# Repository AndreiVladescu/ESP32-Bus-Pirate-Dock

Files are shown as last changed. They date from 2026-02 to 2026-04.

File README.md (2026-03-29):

# ESP32-Bus-Pirate-Dock

Open-source carrier board for the Espressif ESP32-S3 DevKit, designed to complement the [ESP32-Bus-Pirate](https://github.com/geo-tp/ESP32-Bus-Pirate) project.

## Overview

PCB Top

ESP32-Bus-Pirate-Dock is a hardware dock/carrier board for the ESP32-S3 DevKit. It provides level and voltage translation between the 3.3V ESP32-S3 and external peripherals, with support for 1.8V, 3.3V, and 5V operation.

The design is intended to work with original ESP32-S3-DevKitC-1, as well as the wider devkit clones from third party suppliers.

## Hardware status

Current hardware revision: V3

The markings on the PCB for the serial number `V0-YYWW-XXXXX` are as follows: 
- version `0`
- year and week number when these PCBs were produced
- incrementing number of the current batch

An example PCB with these markings would be `V3-2613-00512`, where:
- version number is `3`
- the year is `2026`, and the week is `13`
- this is the `512th` PCB made in that respective week

## Repository contents

- `dock/kicad/` — KiCad design files
- `dock/gerbers/` — PCB fabrication outputs
- `dock/schematic.pdf` — exported schematic reference
- `dock/BOM.csv` — bill of materials
- `3d_models/` — 3D models for the dock and a WIP case
- `images/` — presentation images

## Open-source scope

This repository open-sources the dock hardware design, including:
- schematic and PCB layout source files
- fabrication outputs
- bill of materials
- project documentation and images included in this repository

## Required external parts

This project requires an **ESP32-S3 DevKit to be procured separately by the end user**.

The ESP32-S3 DevKit is a third-party board/module and is **not included** as part of this hardware design repository unless explicitly stated. Vendor silicon, datasheets, trademarks, and separately licensed third-party materials remain the property of their respective owners.

These boards can be acquired through the official Espressif manufacturer and it's stores, or through other third-party websites. If not buying a genuine one,
make sure the dimensions fit one of the header pins on the board.

## PCB Design

### Top View
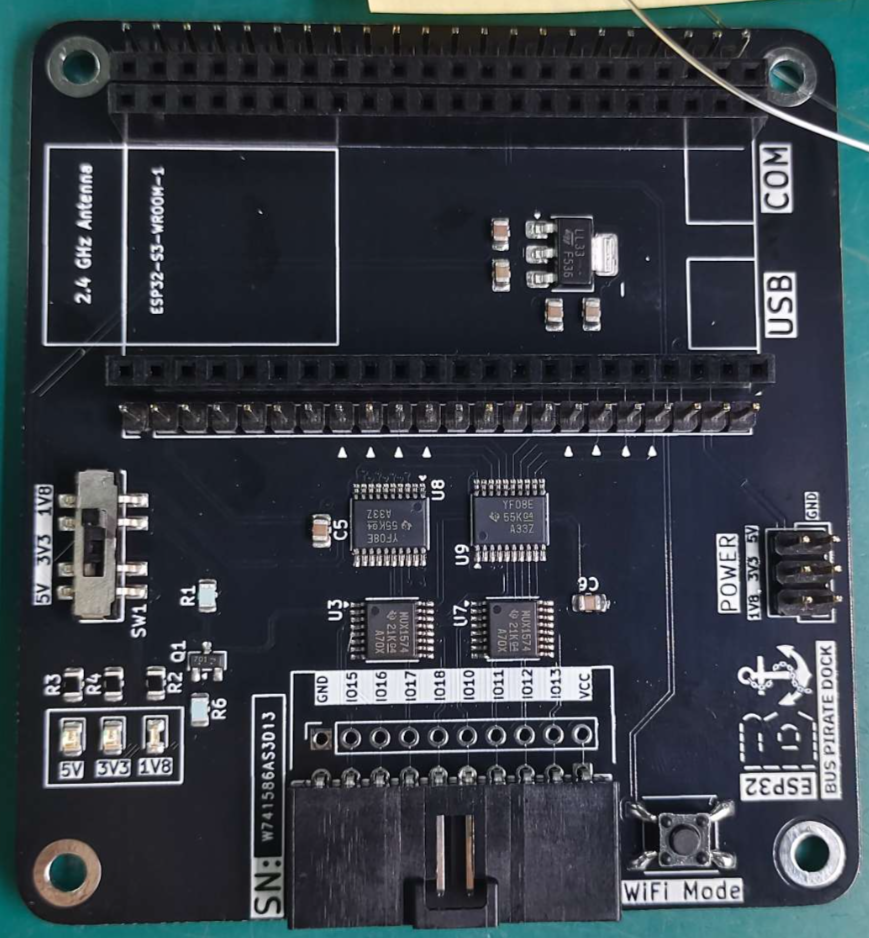
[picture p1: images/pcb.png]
PCB Top


## Current Prototype

### Front Rendering
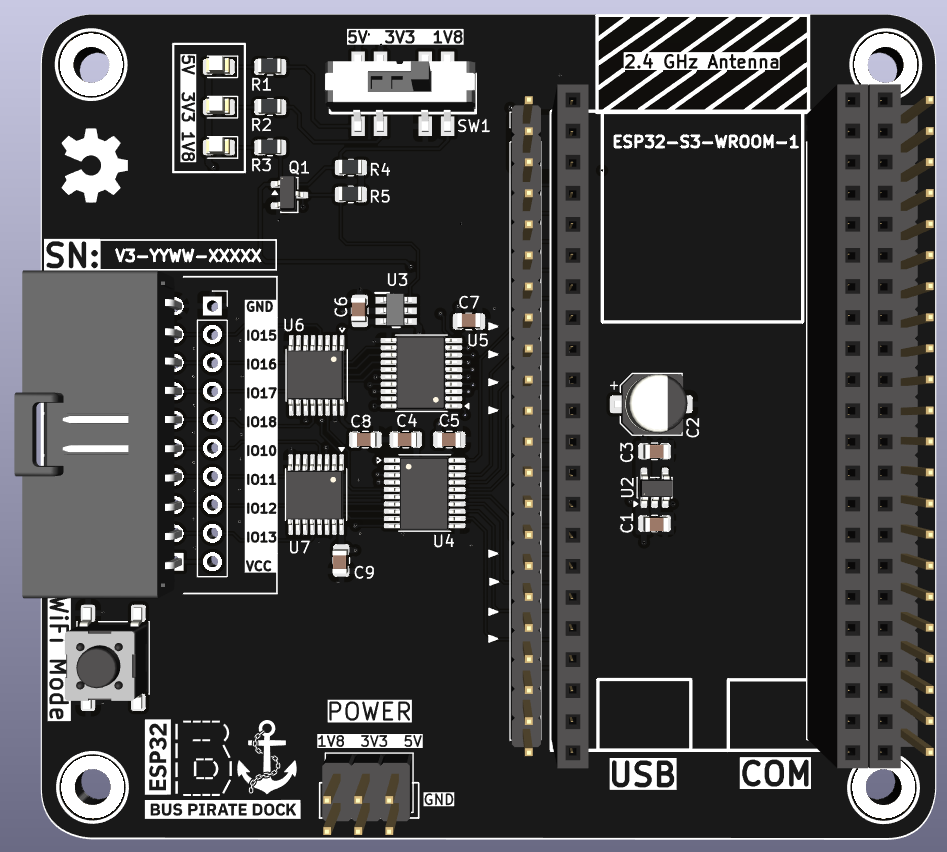
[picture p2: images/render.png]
Front Rendering


### Back Rendering
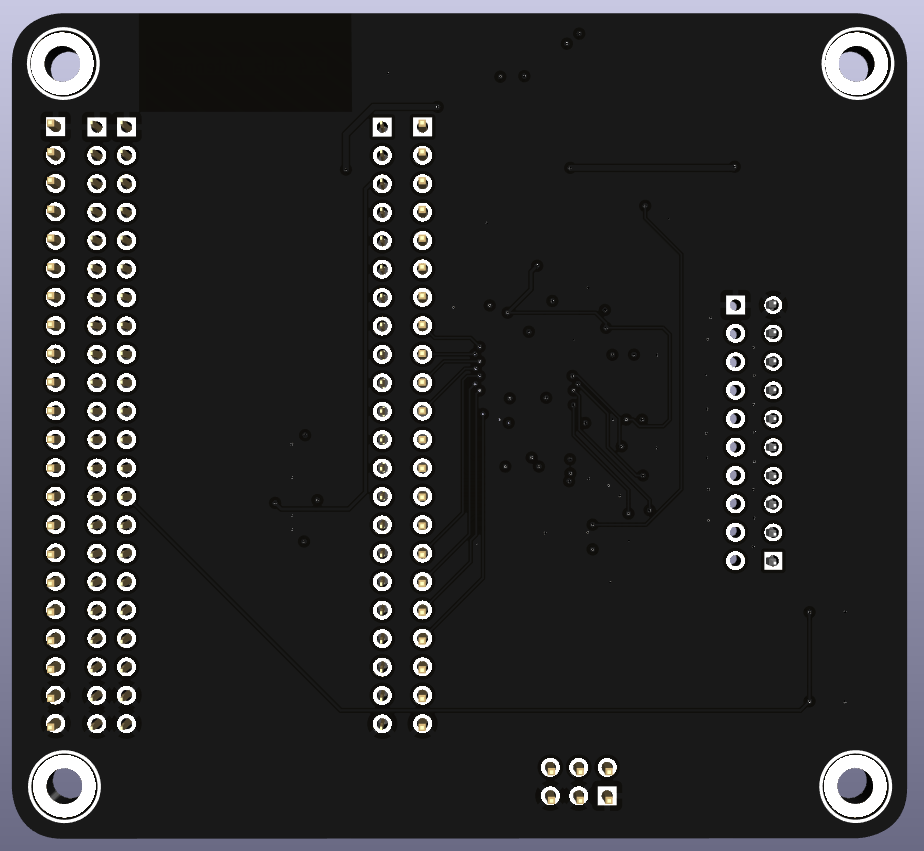
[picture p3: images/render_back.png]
Back Rendering


## Manufacturing and assembly

To fabricate the PCB, use the files in `dock/gerbers/`.

To inspect or modify the design, use the original KiCad source files in `dock/kicad/`.

To source components, use `dock/BOM.csv`.

## Case Design

The case for the ESP32 Bus Pirate Dock is still a work in progress. The current design uses two pieces, which can be printed using an FDM printer with
a 0.4 nozzle.

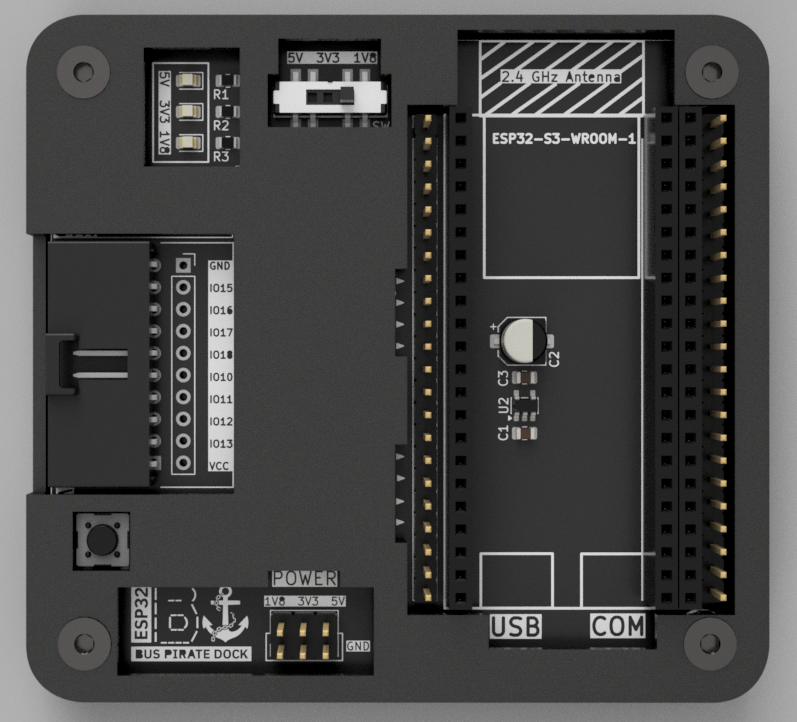
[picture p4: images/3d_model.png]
Case 3D Model

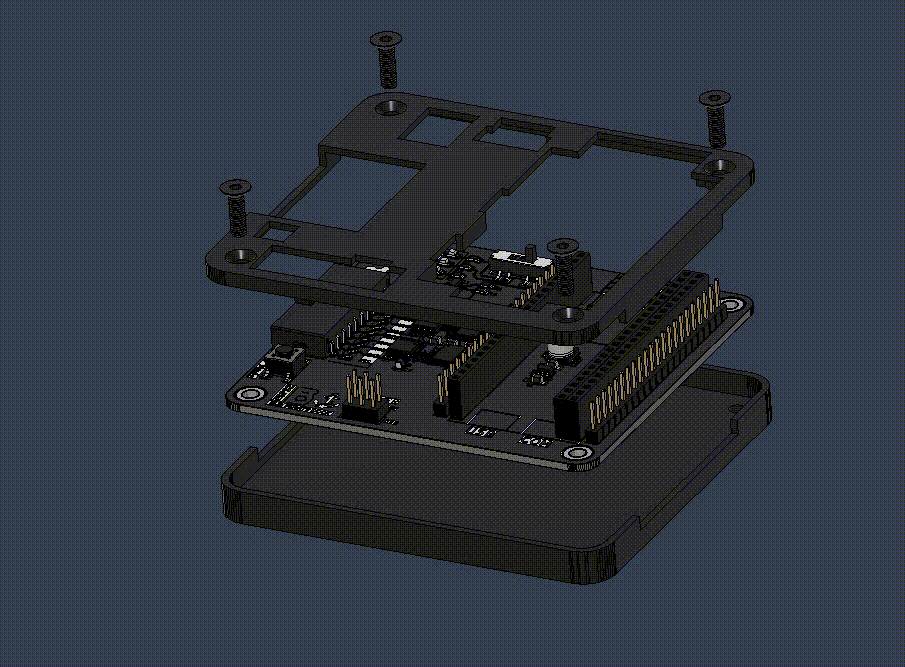
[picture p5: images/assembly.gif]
Dock Assembly


## License

Hardware design files in this repository are licensed under the CERN-OHL-W-2.0 license.
See [LICENSE](LICENSE) for the full license text.

Documentation and images in this repository are licensed under CC BY 4.0 unless otherwise noted.

Any third-party trademarks, datasheets, and separately licensed materials remain the property of their respective owners.

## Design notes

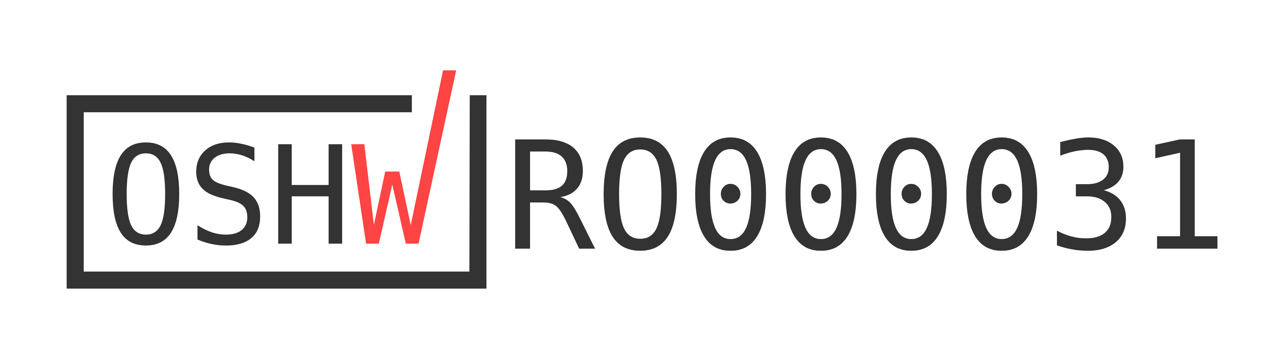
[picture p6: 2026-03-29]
images/certification-mark-RO000031-wide.png

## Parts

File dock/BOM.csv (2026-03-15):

Id | Designator | Footprint | Quantity | Designation | Supplier and ref
1 | SW_1 | SW_SPST_PTS645Sx43SMTR92 | 1 | SW_BOOT
2 | D1 | LED_0805_2012Metric | 1 | RED
3 | C7,C5,C4,C6 | C_0805_2012Metric | 4 | 0.1u
4 | C1,C3 | C_0805_2012Metric | 2 | 1u
5 | C2 | CP_Elec_5x4.5 | 1 | 22u
6 | CN1 | CONN-TH_HX25418-10WA | 1 | HX25418-10WA
7 | J1,J6,J5 | PinSocket_1x22_P2.54mm_Vertical | 3 | Conn_01x22
8 | D2 | LED_0805_2012Metric | 1 | ORANGE
9 | J4,J2 | PinHeader_1x22_P2.54mm_Vertical | 2 | Conn_01x22
10 | U2 | SOT-23-5 | 1 | TLV75518PDBV
11 | C9,C8 | C_0805_2012Metric | 2 | 4.7u
12 | U3 | SOT95P280X145-6N | 1 | TS5A3157DBVR
13 | Q1 | SOT-23 | 1 | 2N7002
14 | R3,R1,R2 | R_0805_2012Metric | 3 | 1k
15 | D3 | LED_0805_2012Metric | 1 | BLUE
16 | R5,R4 | R_0805_2012Metric | 2 | 10k
17 | U7,U6 | TSSOP-16_4.4x5mm_P0.65mm | 2 | TMUX1574PW
18 | SW1 | SW-SMD_8P-L13.0-W3.5-P2.00 | 1 | TA-3532S-A2
19 | U4,U5 | Texas_PW0020A_TSSOP-20_4.4x6.5mm_P0.65mm | 2 | TXS0108EPW
20 | J7 | PinHeader_2x03_P2.54mm_Vertical | 1 | Conn_02x03

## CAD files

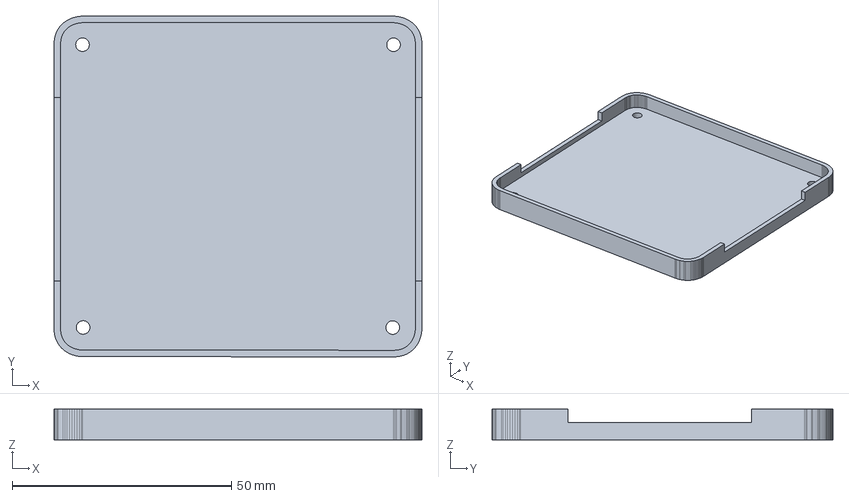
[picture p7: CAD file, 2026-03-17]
dock/3d_models/Bottom Case.step
84.0 x 77.8 x 7.01 mm

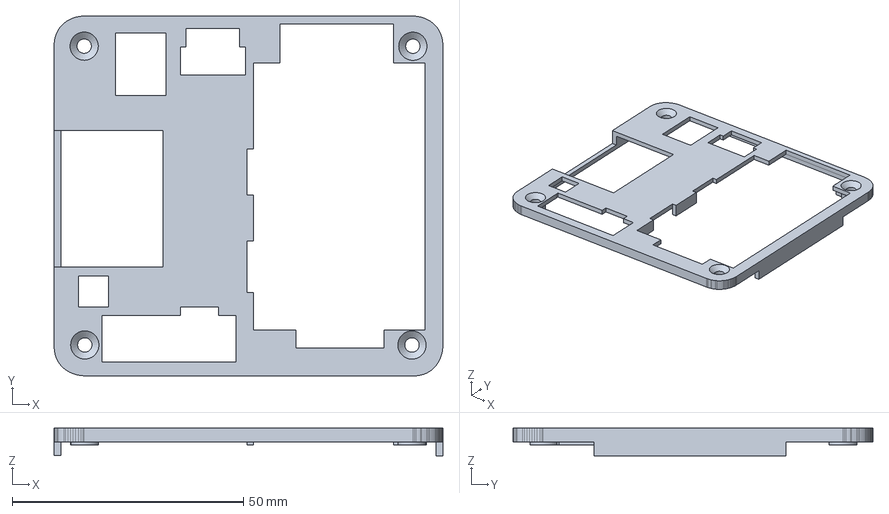
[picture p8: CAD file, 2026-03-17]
dock/3d_models/Top Case.step
84.0 x 77.8 x 6.00 mm

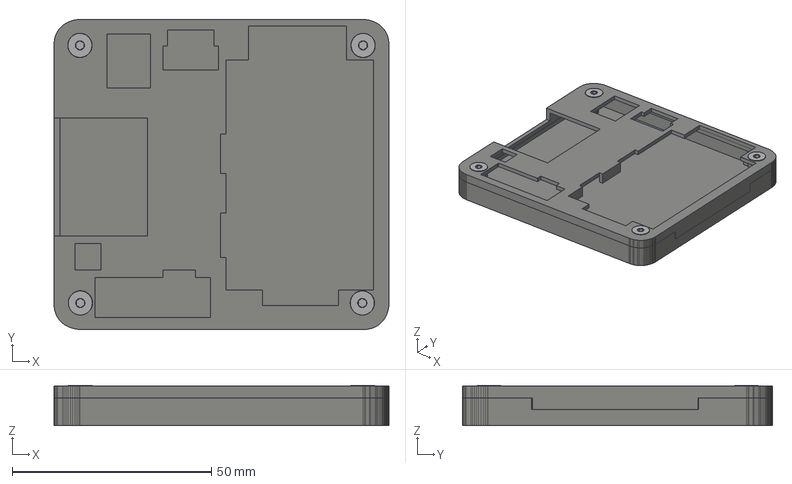
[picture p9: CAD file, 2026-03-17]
dock/3d_models/enclosure.step
84.0 x 77.8 x 10.2 mm
91294A132_Black-Oxide Alloy Steel Hex Drive Flat Head Screw x 4
Bottom Case
Top Case

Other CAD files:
dock/3d_models/Bottom Case.stl
dock/3d_models/Top Case.stl

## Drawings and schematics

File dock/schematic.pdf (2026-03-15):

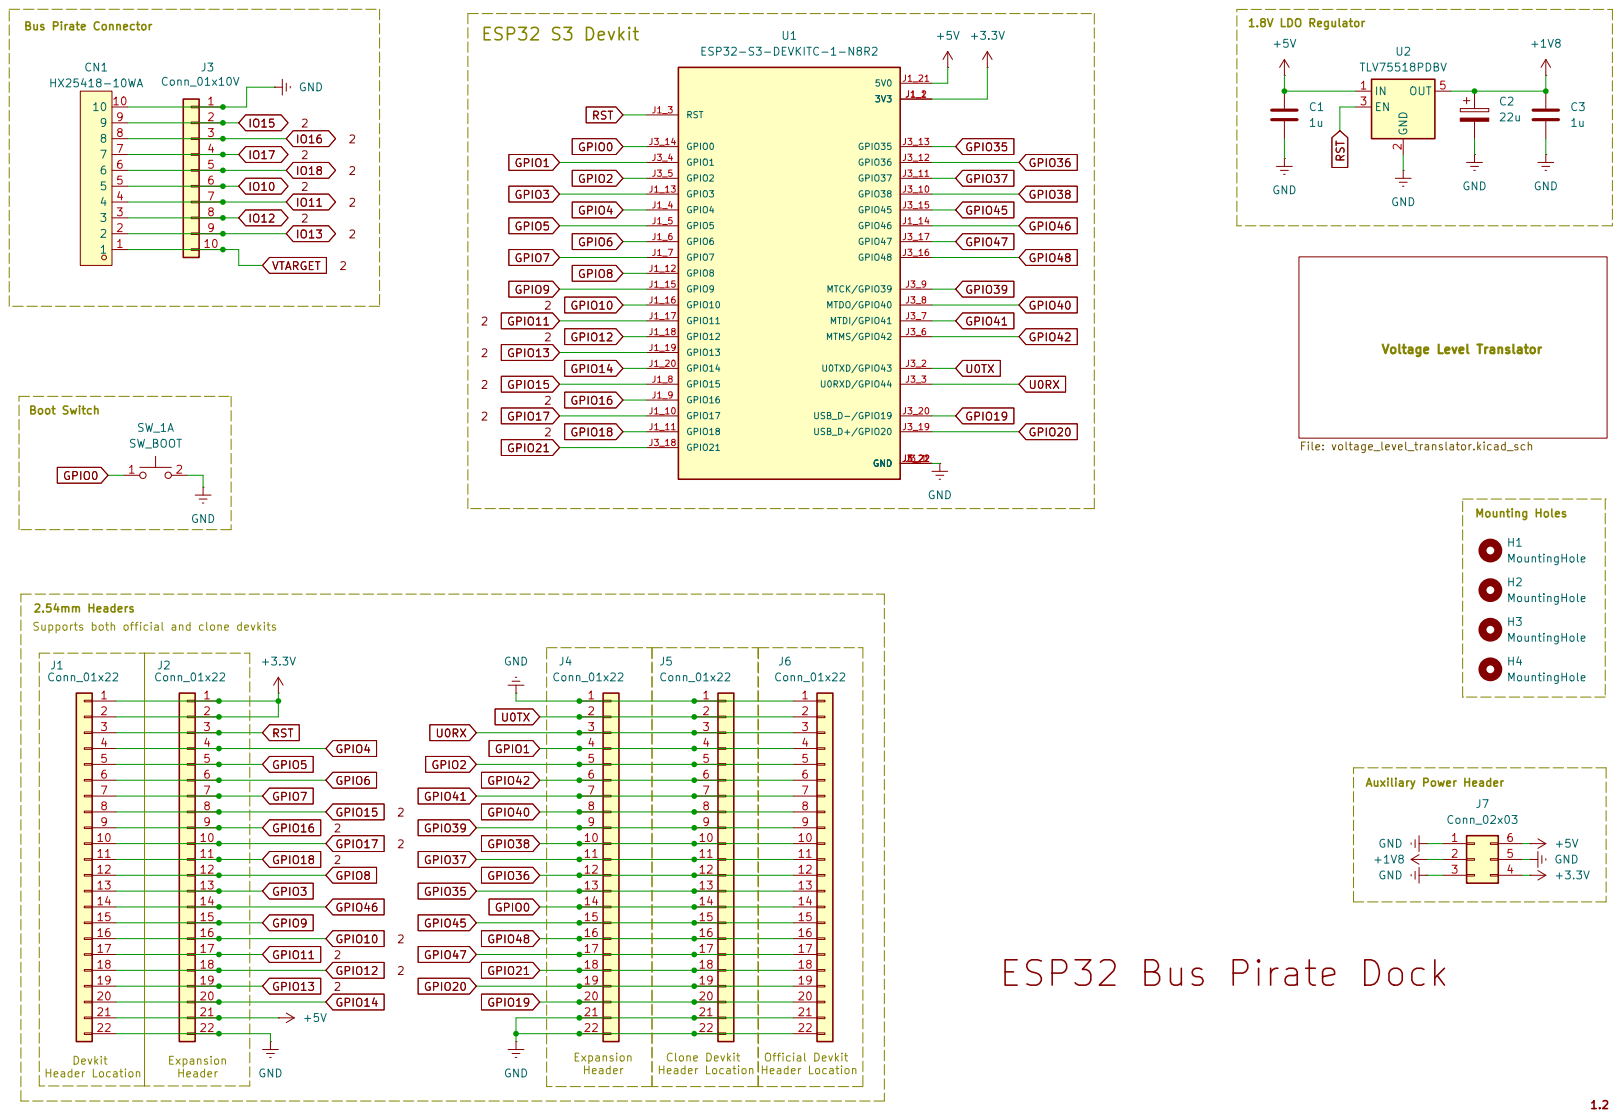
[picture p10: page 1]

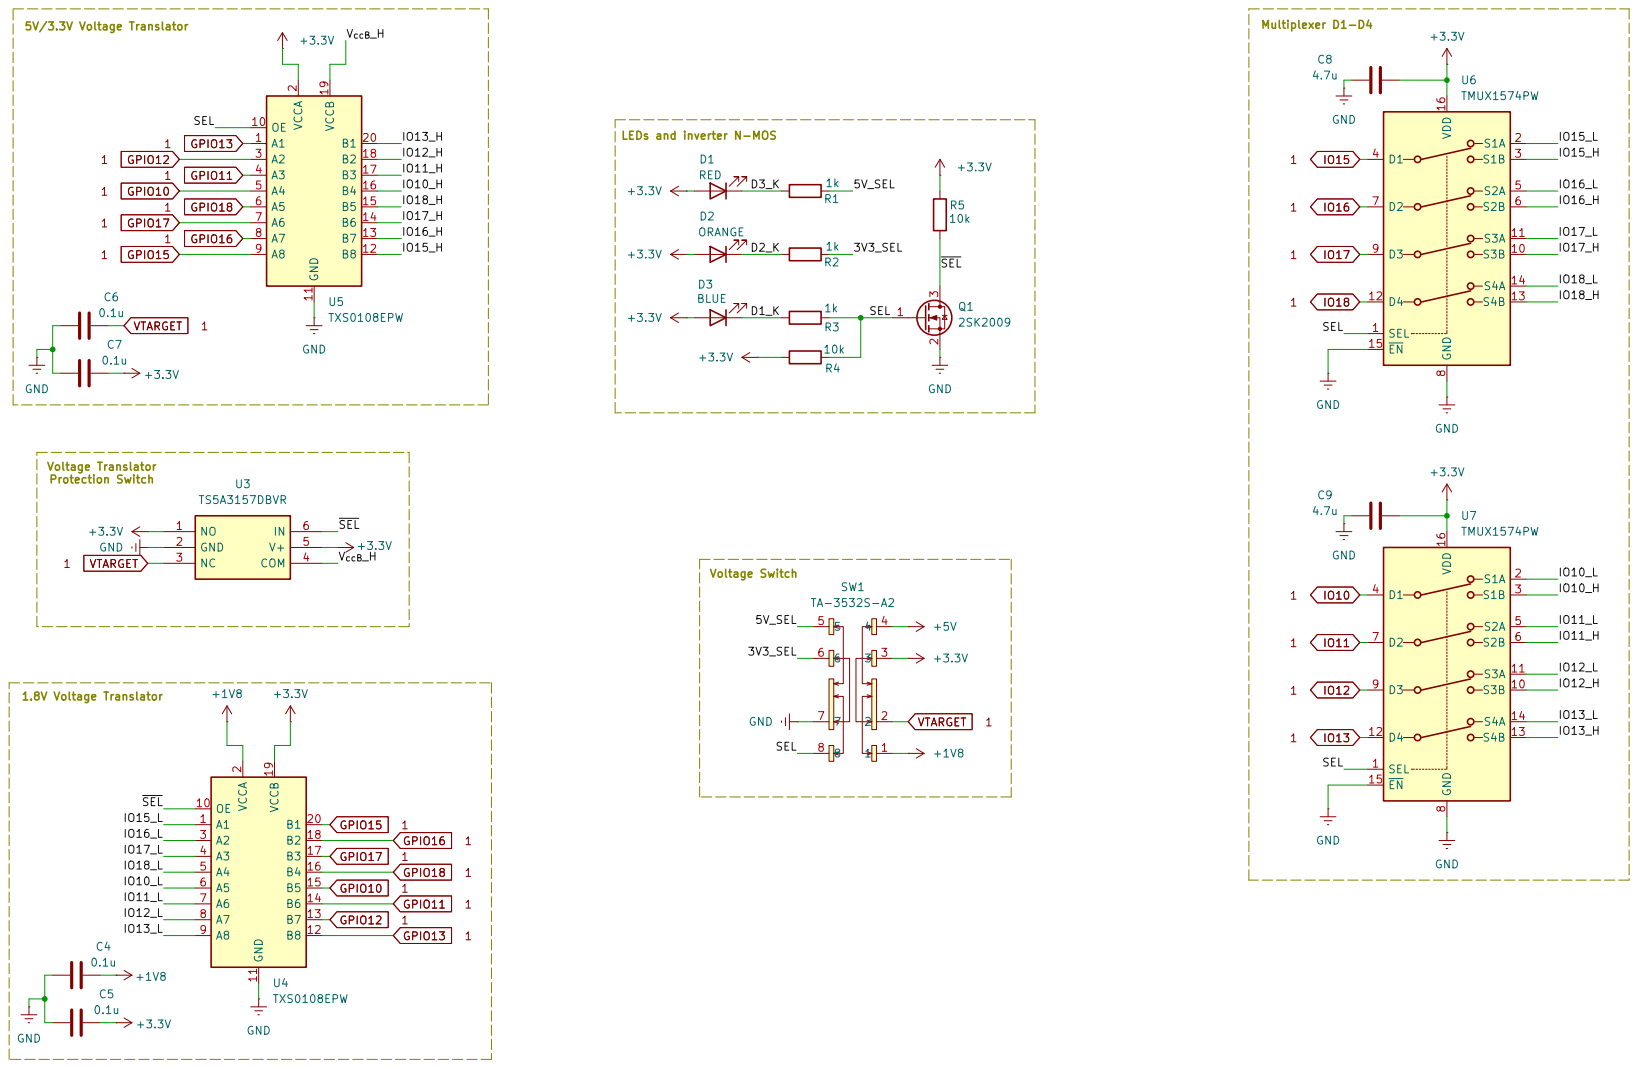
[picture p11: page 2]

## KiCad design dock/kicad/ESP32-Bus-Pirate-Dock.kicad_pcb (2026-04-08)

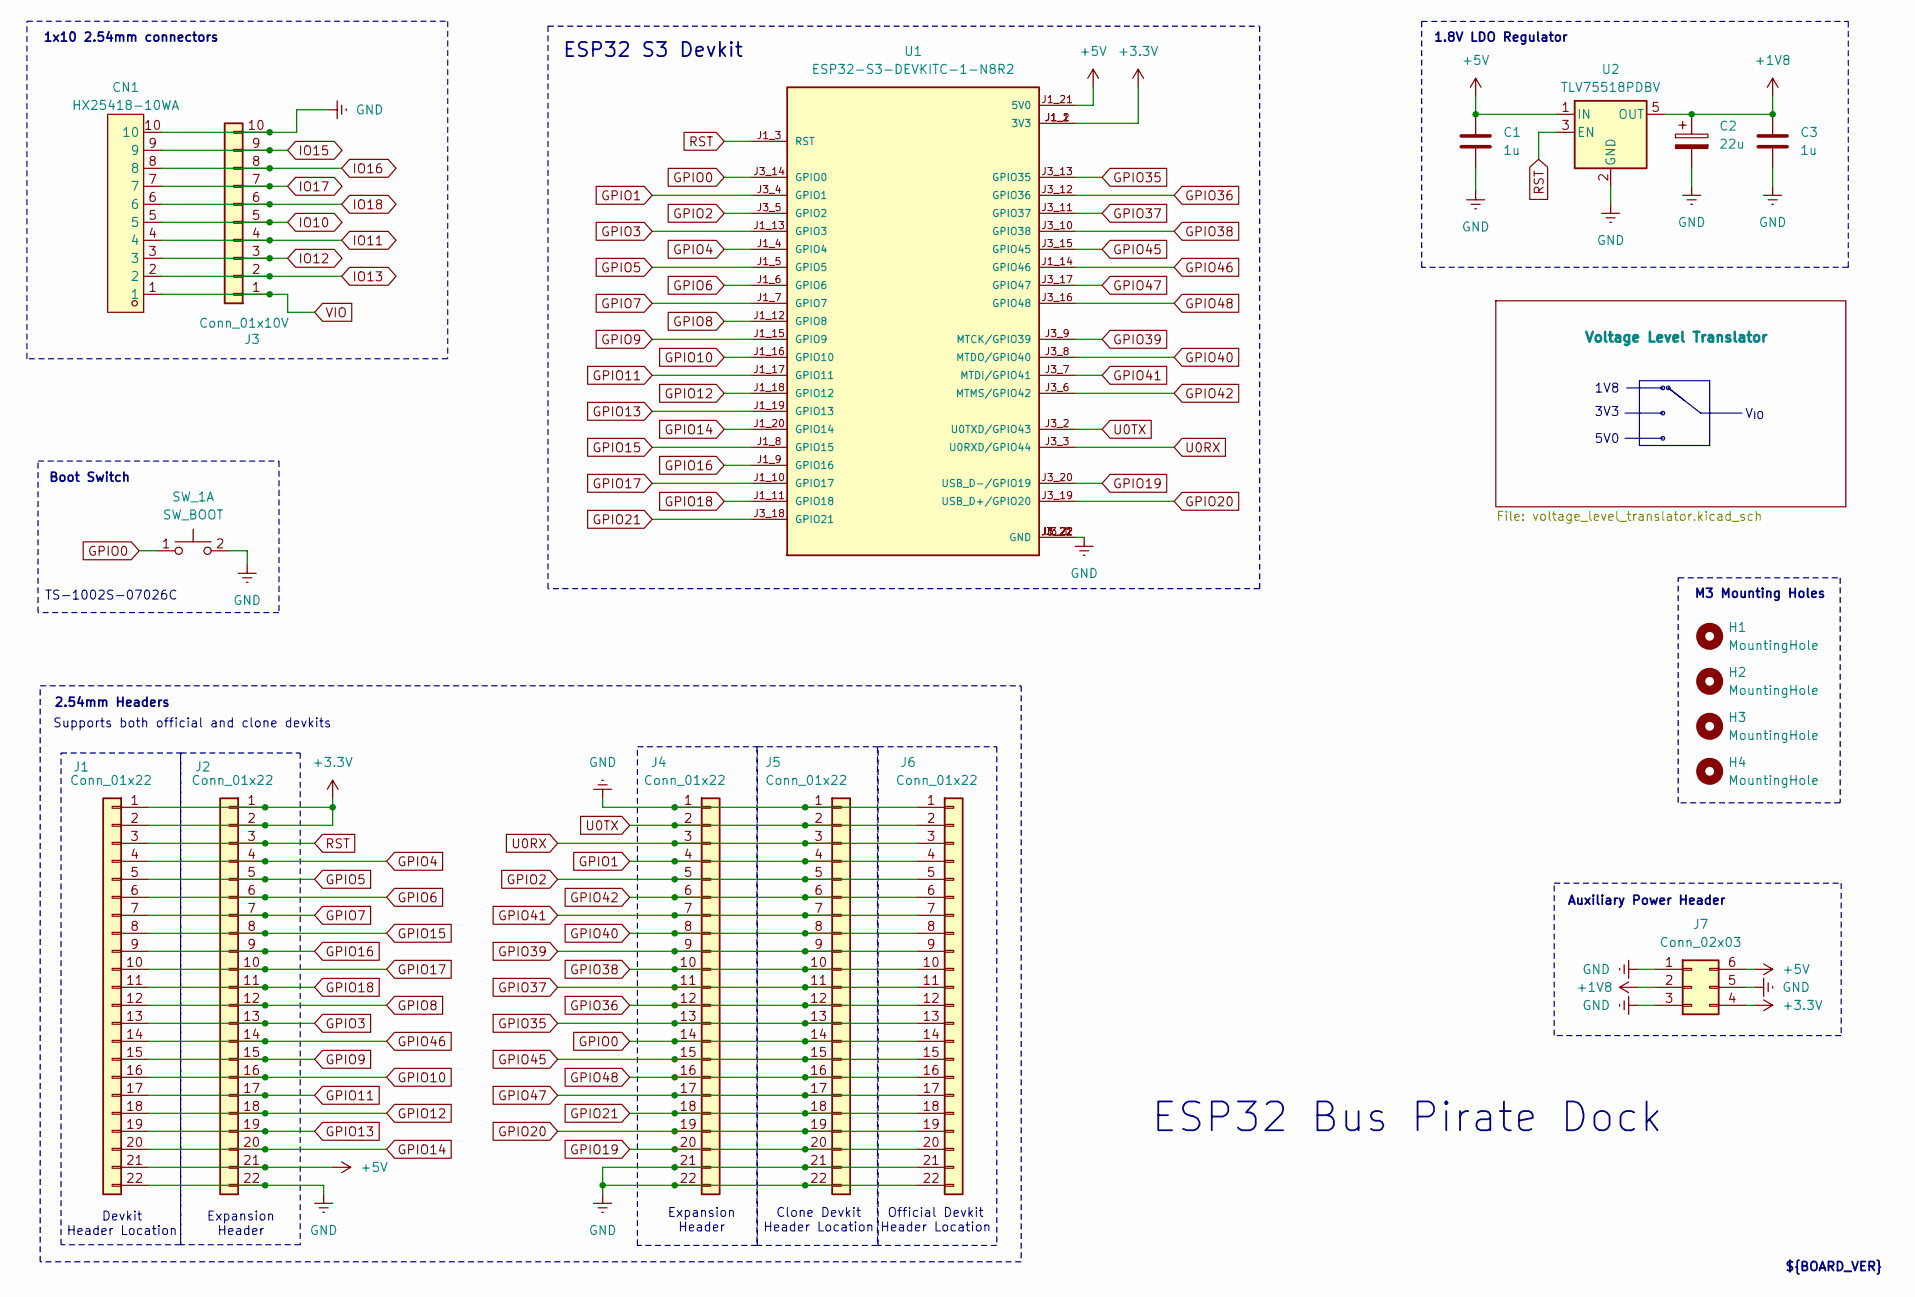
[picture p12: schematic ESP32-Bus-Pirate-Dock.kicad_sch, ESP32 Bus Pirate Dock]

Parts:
C1, C3: 1u; C_0805_2012Metric
C2: 22u; CP_Elec_5x4.5
CN1: HX25418-10WA; CONN-TH_HX25418-10WA; LCSC Part C704586
H1, H2, H3, H4: MountingHole; MountingHole_3.2mm_M3_DIN965_Pad_TopBottom
J1, J5, J6: Conn_01x22; PinSocket_1x22_P2.54mm_Vertical
J2, J4: Conn_01x22; PinHeader_1x22_P2.54mm_Vertical
J3: Conn_01x10V; PinSocket_1x10_P2.54mm_Vertical
J7: Conn_02x03; PinHeader_2x03_P2.54mm_Vertical
SW_1: SW_BOOT; SW_SPST_PTS645Sx43SMTR92
U1: ESP32-S3-DEVKITC-1-N8R2; XCVR_ESP32-S3-DEVKITC-1-N8R2; PARTREV V1
U2: TLV75518PDBV; SOT-23-5

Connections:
+1V8: C2.1, C3.1, J7.2, U2.5 (OUT); also elsewhere on the board
+3.3V: J1.1, J1.2, J2.1, J2.2, J7.4, U1.J1_1 (3V3), U1.J1_2 (3V3); also elsewhere on the board
+5V: C1.1, J1.21, J2.21, J7.6, U1.J1_21 (5V0), U2.1 (IN); also elsewhere on the board
GND: C1.2, C2.2, C3.2, CN1.10, J1.22, J2.22, J3.10, J4.1, J4.21, J4.22, J5.1, J5.21, J5.22, J6.1, J6.21, J6.22, J7.1, J7.3, J7.5, SW_1.2 (D), U1.J1_22 (GND), U1.J3_1 (GND), U1.J3_21 (GND), U1.J3_22 (GND), U2.2 (GND); also elsewhere on the board
GPIO0: J4.14, J5.14, J6.14, SW_1.1 (C), U1.J3_14 (GPIO0)
GPIO1: J4.4, J5.4, J6.4, U1.J3_4 (GPIO1)
GPIO2: J4.5, J5.5, J6.5, U1.J3_5 (GPIO2)
GPIO3: J1.13, J2.13, U1.J1_13 (GPIO3)
GPIO4: J1.4, J2.4, U1.J1_4 (GPIO4)
GPIO5: J1.5, J2.5, U1.J1_5 (GPIO5)
GPIO6: J1.6, J2.6, U1.J1_6 (GPIO6)
GPIO7: J1.7, J2.7, U1.J1_7 (GPIO7)
GPIO8: J1.12, J2.12, U1.J1_12 (GPIO8)
GPIO9: J1.15, J2.15, U1.J1_15 (GPIO9)
GPIO10: J1.16, J2.16, U1.J1_16 (GPIO10); also elsewhere on the board
GPIO11: J1.17, J2.17, U1.J1_17 (GPIO11); also elsewhere on the board
GPIO12: J1.18, J2.18, U1.J1_18 (GPIO12); also elsewhere on the board
GPIO13: J1.19, J2.19, U1.J1_19 (GPIO13); also elsewhere on the board
GPIO14: J1.20, J2.20, U1.J1_20 (GPIO14)
GPIO15: J1.8, J2.8, U1.J1_8 (GPIO15); also elsewhere on the board
GPIO16: J1.9, J2.9, U1.J1_9 (GPIO16); also elsewhere on the board
GPIO17: J1.10, J2.10, U1.J1_10 (GPIO17); also elsewhere on the board
GPIO18: J1.11, J2.11, U1.J1_11 (GPIO18); also elsewhere on the board
GPIO19: J4.20, J5.20, J6.20, U1.J3_20 (USB_D-/GPIO19)
GPIO20: J4.19, J5.19, J6.19, U1.J3_19 (USB_D+/GPIO20)
GPIO21: J4.18, J5.18, J6.18, U1.J3_18 (GPIO21)
GPIO35: J4.13, J5.13, J6.13, U1.J3_13 (GPIO35)
GPIO36: J4.12, J5.12, J6.12, U1.J3_12 (GPIO36)
GPIO37: J4.11, J5.11, J6.11, U1.J3_11 (GPIO37)
GPIO38: J4.10, J5.10, J6.10, U1.J3_10 (GPIO38)
GPIO39: J4.9, J5.9, J6.9, U1.J3_9 (MTCK/GPIO39)
GPIO40: J4.8, J5.8, J6.8, U1.J3_8 (MTDO/GPIO40)
GPIO41: J4.7, J5.7, J6.7, U1.J3_7 (MTDI/GPIO41)
GPIO42: J4.6, J5.6, J6.6, U1.J3_6 (MTMS/GPIO42)
GPIO45: J4.15, J5.15, J6.15, U1.J3_15 (GPIO45)
GPIO46: J1.14, J2.14, U1.J1_14 (GPIO46)
GPIO47: J4.17, J5.17, J6.17, U1.J3_17 (GPIO47)
GPIO48: J4.16, J5.16, J6.16, U1.J3_16 (GPIO48)
IO10: CN1.5, J3.5; also elsewhere on the board
IO11: CN1.4, J3.4; also elsewhere on the board
IO12: CN1.3, J3.3; also elsewhere on the board
IO13: CN1.2, J3.2; also elsewhere on the board
IO15: CN1.9, J3.9; also elsewhere on the board
IO16: CN1.8, J3.8; also elsewhere on the board
IO17: CN1.7, J3.7; also elsewhere on the board
IO18: CN1.6, J3.6; also elsewhere on the board
RST: J1.3, J2.3, U1.J1_3 (RST), U2.3 (EN)
U0RX: J4.3, J5.3, J6.3, U1.J3_3 (U0RXD/GPIO44)
U0TX: J4.2, J5.2, J6.2, U1.J3_2 (U0TXD/GPIO43)
VIO: CN1.1, J3.1; also elsewhere on the board

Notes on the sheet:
Boot Switch
M3 Mounting Holes
${BOARD_VER}
1.8V LDO Regulator
TS-1002S-07026C
1x10 2.54mm connectors
Auxiliary Power Header
Clone Devkit Header Location
Expansion Header
Official Devkit Header Location
2.54mm Headers
Devkit Header Location
5V0
3V3
ESP32 S3 Devkit
1V8
V_{IO}
Supports both official and clone devkits
ESP32 Bus Pirate Dock

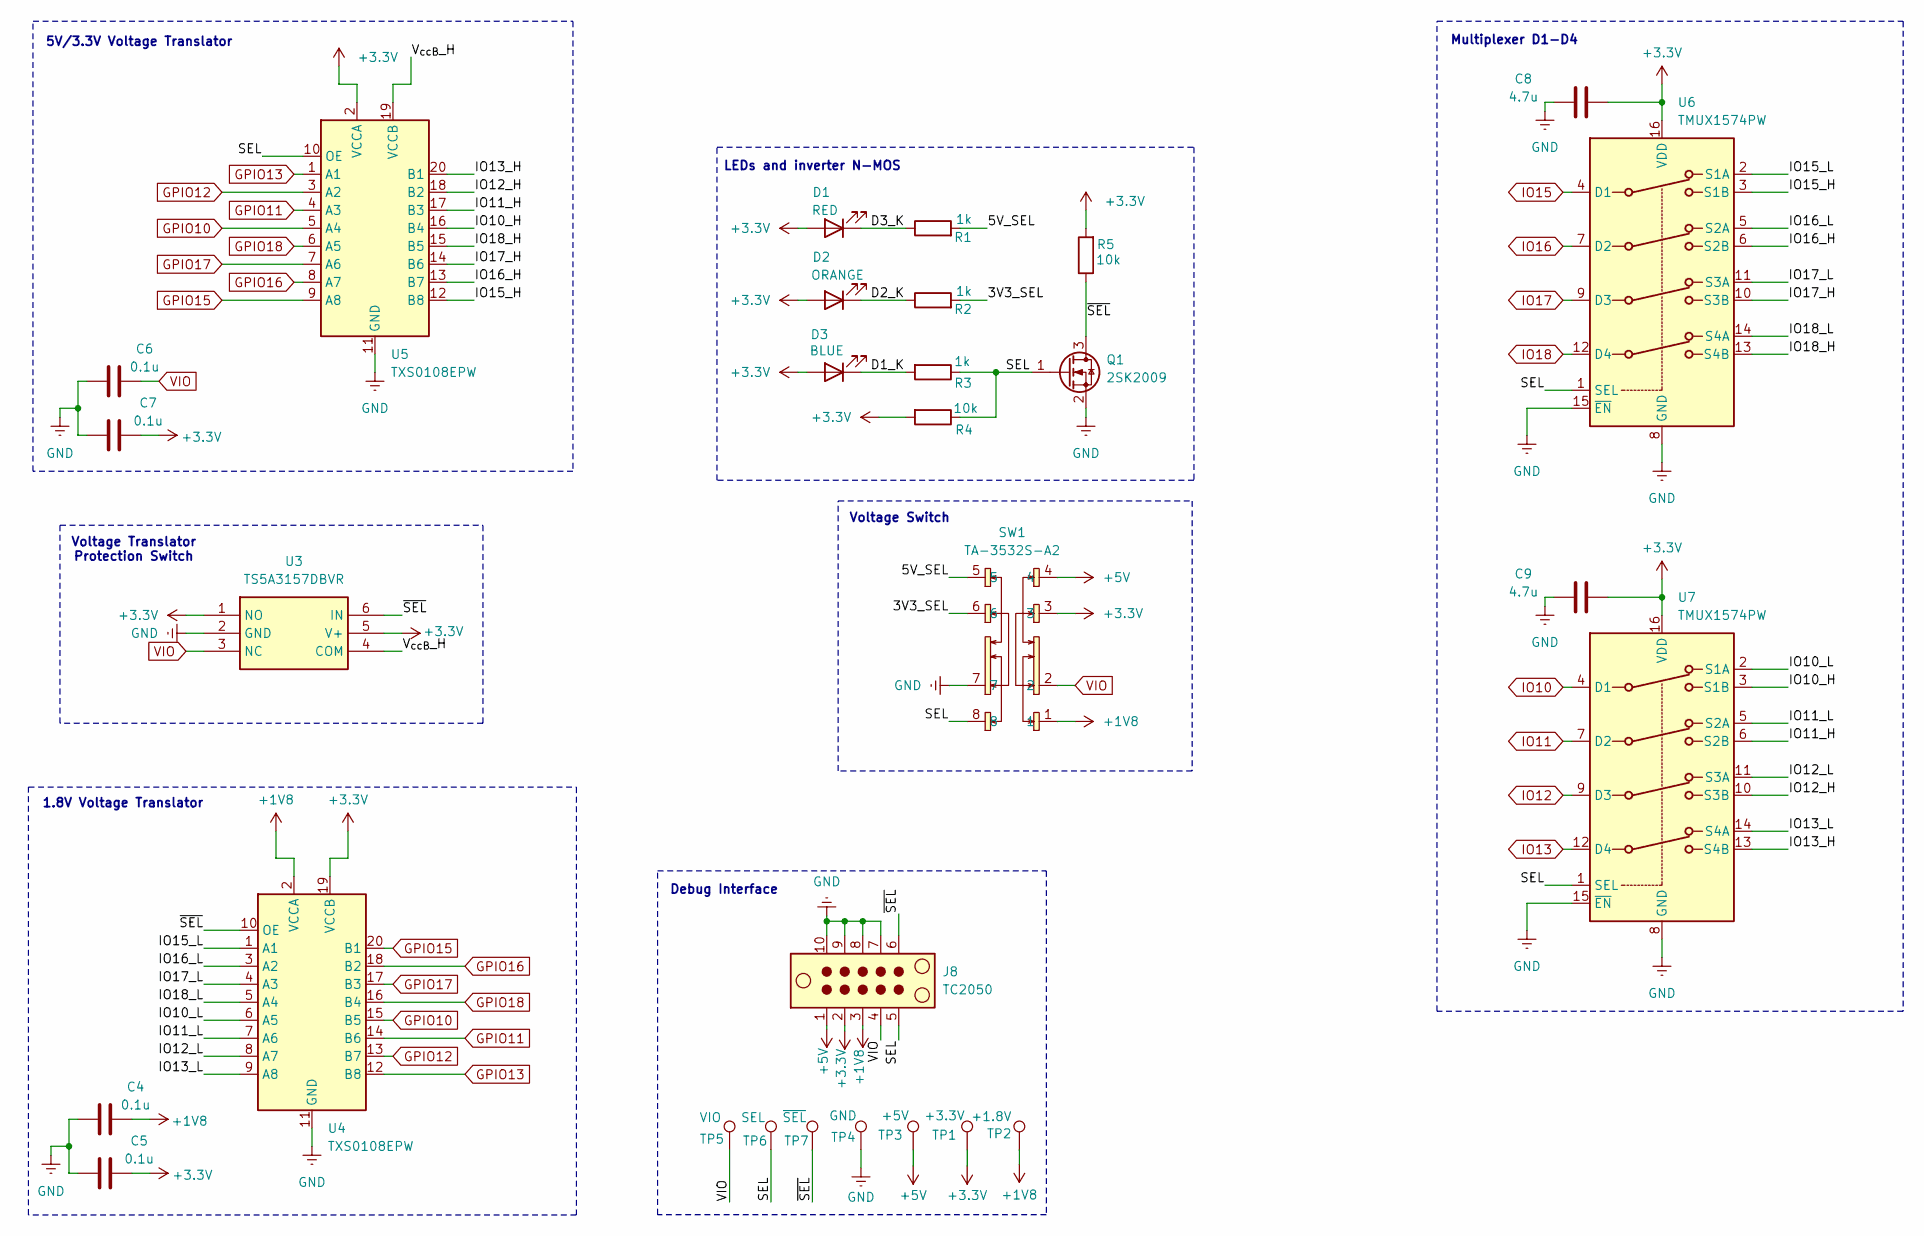
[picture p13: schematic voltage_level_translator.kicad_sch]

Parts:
C4, C5, C6, C7: 0.1u; C_0805_2012Metric
C8, C9: 4.7u; C_0805_2012Metric
D1: RED; LED_0805_2012Metric
D2: ORANGE; LED_0805_2012Metric
D3: BLUE; LED_0805_2012Metric
J8: TC2050; Tag-Connect_TC2050-IDC-NL_2x05_P1.27mm_Vertical_with_bottom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
Q1: 2SK2009; SOT-23
R1, R2, R3: 1k; R_0805_2012Metric
R4, R5: 10k; R_0805_2012Metric
SW1: TA-3532S-A2; SW-SMD_8P-L13.0-W3.5-P2.00; LCSC Part C514040
TP1: +3.3V; TestPoint_Pad_D1.0mm
TP2: +1.8V; TestPoint_Pad_D1.0mm
TP3: +5V; TestPoint_Pad_D1.0mm
TP4: GND; TestPoint_Pad_D1.0mm
TP5: VIO; TestPoint_Pad_D1.0mm
TP6: SEL; TestPoint_Pad_D1.0mm
TP7: ~{SEL}; TestPoint_Pad_D1.0mm
U3: TS5A3157DBVR; SOT95P280X145-6N; Mouser Part Number 595-TS5A3157DBVR
U4, U5: TXS0108EPW; Texas_PW0020A_TSSOP-20_4.4x6.5mm_P0.65mm
U6, U7: TMUX1574PW; TSSOP-16_4.4x5mm_P0.65mm

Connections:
+1V8: C4.1, J8.3, SW1.1, TP2.1, U4.2 (VCCA); also elsewhere on the board
+3.3V: C5.1, C7.1, C8.1, C9.1, D1.2 (A), D2.2 (A), D3.2 (A), J8.2, R4.2, R5.2, SW1.3, TP1.1, U3.1 (NO), U3.5 (V+), U4.19 (VCCB), U5.2 (VCCA), U6.16 (VDD), U7.16 (VDD); also elsewhere on the board
+5V: J8.1, SW1.4, TP3.1; also elsewhere on the board
/Voltage Level Translator/3V3_SEL: R2.2, SW1.6
/Voltage Level Translator/5V_SEL: R1.2, SW1.5
/Voltage Level Translator/D1_K: D3.1 (K), R3.2
/Voltage Level Translator/D2_K: D2.1 (K), R2.1
/Voltage Level Translator/D3_K: D1.1 (K), R1.1
/Voltage Level Translator/IO10_H: U5.16 (B4), U7.3 (S1B)
/Voltage Level Translator/IO10_L: U4.6 (A5), U7.2 (S1A)
/Voltage Level Translator/IO11_H: U5.17 (B3), U7.6 (S2B)
/Voltage Level Translator/IO11_L: U4.7 (A6), U7.5 (S2A)
/Voltage Level Translator/IO12_H: U5.18 (B2), U7.10 (S3B)
/Voltage Level Translator/IO12_L: U4.8 (A7), U7.11 (S3A)
/Voltage Level Translator/IO13_H: U5.20 (B1), U7.13 (S4B)
/Voltage Level Translator/IO13_L: U4.9 (A8), U7.14 (S4A)
/Voltage Level Translator/IO15_H: U5.12 (B8), U6.3 (S1B)
/Voltage Level Translator/IO15_L: U4.1 (A1), U6.2 (S1A)
/Voltage Level Translator/IO16_H: U5.13 (B7), U6.6 (S2B)
/Voltage Level Translator/IO16_L: U4.3 (A2), U6.5 (S2A)
/Voltage Level Translator/IO17_H: U5.14 (B6), U6.10 (S3B)
/Voltage Level Translator/IO17_L: U4.4 (A3), U6.11 (S3A)
/Voltage Level Translator/IO18_H: U5.15 (B5), U6.13 (S4B)
/Voltage Level Translator/IO18_L: U4.5 (A4), U6.14 (S4A)
/Voltage Level Translator/SEL: J8.5, Q1.1 (G), R3.1, R4.1, SW1.8, TP6.1, U5.10 (OE), U6.1 (SEL), U7.1 (SEL)
/Voltage Level Translator/V_{ccB}_H: U3.4 (COM), U5.19 (VCCB)
/Voltage Level Translator/~SEL: J8.6, Q1.3 (D), R5.1, TP7.1, U3.6 (IN), U4.10 (OE)
GND: C4.2, C5.2, C6.2, C7.2, C8.2, C9.2, J8.7, J8.8, J8.9, J8.10, Q1.2 (S), SW1.7, TP4.1, U3.2 (GND), U4.11 (GND), U5.11 (GND), U6.8 (GND), U6.15 (~EN), U7.8 (GND), U7.15 (~EN); also elsewhere on the board
GPIO10: U4.15 (B5), U5.5 (A4); also elsewhere on the board
GPIO11: U4.14 (B6), U5.4 (A3); also elsewhere on the board
GPIO12: U4.13 (B7), U5.3 (A2); also elsewhere on the board
GPIO13: U4.12 (B8), U5.1 (A1); also elsewhere on the board
GPIO15: U4.20 (B1), U5.9 (A8); also elsewhere on the board
GPIO16: U4.18 (B2), U5.8 (A7); also elsewhere on the board
GPIO17: U4.17 (B3), U5.7 (A6); also elsewhere on the board
GPIO18: U4.16 (B4), U5.6 (A5); also elsewhere on the board
IO10: U7.4 (D1); also elsewhere on the board
IO11: U7.7 (D2); also elsewhere on the board
IO12: U7.9 (D3); also elsewhere on the board
IO13: U7.12 (D4); also elsewhere on the board
IO15: U6.4 (D1); also elsewhere on the board
IO16: U6.7 (D2); also elsewhere on the board
IO17: U6.9 (D3); also elsewhere on the board
IO18: U6.12 (D4); also elsewhere on the board
VIO: C6.1, J8.4, SW1.2, TP5.1, U3.3 (NC); also elsewhere on the board

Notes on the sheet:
5V/3.3V Voltage Translator
Voltage Switch
LEDs and inverter N-MOS
Debug Interface
Voltage Translator Protection Switch
Multiplexer D1-D4
1.8V Voltage Translator

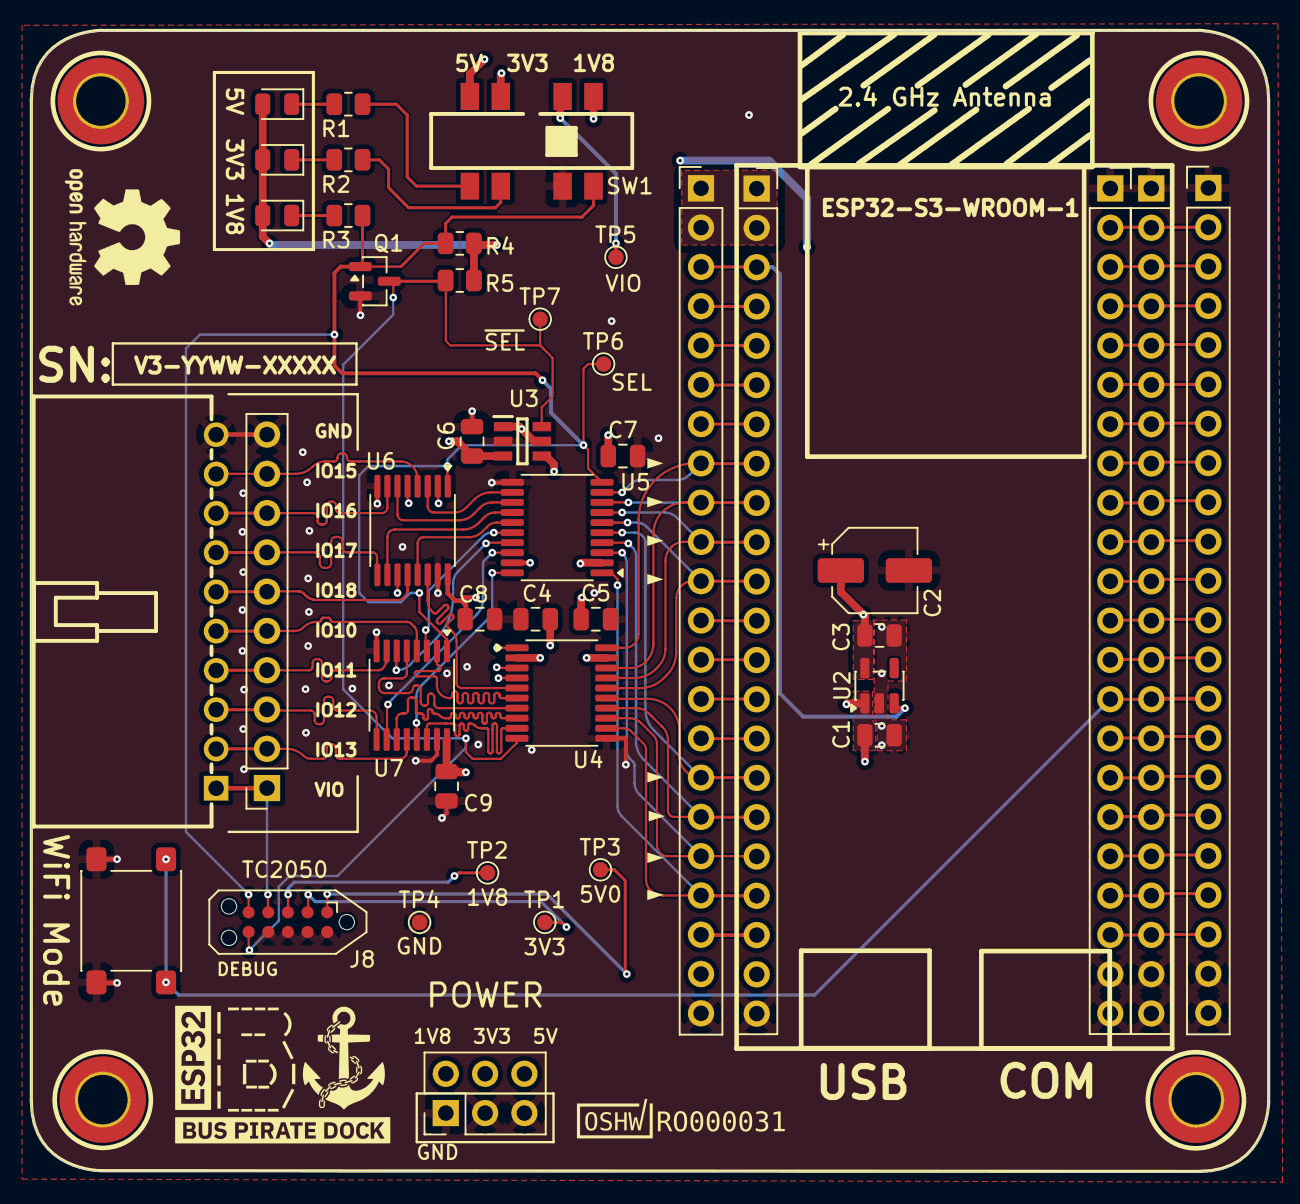
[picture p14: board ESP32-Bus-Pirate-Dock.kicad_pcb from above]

Board: 4 copper layers, 80.0 x 73.8 mm, 46 parts (0 on the bottom side), 74 nets.

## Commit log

2025-09-21 Added initial proto board
    [ESP32-Bus-Pirate-Dock.kicad_pcb, ESP32-Bus-Pirate-Dock.kicad_sch]
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2025-09-24 Modified schematic and PCB
    [ESP32-Bus-Pirate-Dock.kicad_pcb, ESP32-Bus-Pirate-Dock.kicad_sch]
2025-09-24 Added 1.8V and another buttons
    [ESP32-Bus-Pirate-Dock.kicad_sch]
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2025-09-27 Added logic level shifting
    [ESP32-Bus-Pirate-Dock.kicad_pcb, ESP32-Bus-Pirate-Dock.kicad_sch]
2025-09-27 PCB modifications
    - removed RESET switch
    - re-arranged FXMA108 pins
    [ESP32-Bus-Pirate-Dock.kicad_pcb, ESP32-Bus-Pirate-Dock.kicad_sch]
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2025-09-27 Added DP3T switch in schematic
    [ESP32-Bus-Pirate-Dock.kicad_pcb, ESP32-Bus-Pirate-Dock.kicad_sch]
2025-09-28 Added LEDs for voltage selection and DP3T switch
    [ESP32-Bus-Pirate-Dock.kicad_pcb, ESP32-Bus-Pirate-Dock.kicad_sch]
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2025-09-29 Fully routed PCB prototype
    [ESP32-Bus-Pirate-Dock.kicad_pcb]
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2025-09-30 Fixed connector polarity
    [ESP32-Bus-Pirate-Dock.kicad_pcb, ESP32-Bus-Pirate-Dock.kicad_sch]
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2025-10-02 Modified for PCBWay prototype
    [ESP32-Bus-Pirate-Dock.kicad_pcb]
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2025-11-23 Added switch 3D model
    [ESP32-Bus-Pirate-Dock.kicad_pcb]
2025-11-23 Added separate power connector
    [ESP32-Bus-Pirate-Dock.kicad_pcb, ESP32-Bus-Pirate-Dock.kicad_sch]
2025-11-23 Updated power conn graphics
    [ESP32-Bus-Pirate-Dock.kicad_pcb, ESP32-Bus-Pirate-Dock.kicad_sch]
2025-11-24 Updated PCB & Logo
    [ESP32-Bus-Pirate-Dock.kicad_pcb, ESP32-Bus-Pirate-Dock.kicad_sch]
2025-11-24 Completed wiring for V2
    [ESP32-Bus-Pirate-Dock.kicad_pcb]
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2025-11-24 Via & Ground pour touchups
    [ESP32-Bus-Pirate-Dock.kicad_pcb, ESP32-Bus-Pirate-Dock.kicad_sch]
2025-11-24 Added devkit
    Added official devkit for mockup
    [ESP32-Bus-Pirate-Dock.kicad_pcb, ESP32-Bus-Pirate-Dock.kicad_sch]
2025-11-28 Adapted board to unofficial and official devkit versions
    [ESP32-Bus-Pirate-Dock.kicad_pcb, ESP32-Bus-Pirate-Dock.kicad_sch]
2025-11-28 Updated schematic for hybrid devkit
    [ESP32-Bus-Pirate-Dock.kicad_sch]
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2025-11-28 Wired up LSF0108 Voltage Translator
    [ESP32-Bus-Pirate-Dock.kicad_pcb, ESP32-Bus-Pirate-Dock.kicad_sch, voltage_level_translator.kicad_sch]
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2025-11-28 Added LSF1080 PCB placeholders
    [ESP32-Bus-Pirate-Dock.kicad_pcb, ESP32-Bus-Pirate-Dock.kicad_sch, voltage_level_translator.kicad_sch]
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2025-12-03 Fixed board outline
    [ESP32-Bus-Pirate-Dock.kicad_pcb]
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2025-12-11 Updated enable logic for translators
    [voltage_level_translator.kicad_sch]
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2025-12-15 Updated PCB to include TXS disabling
    [ESP32-Bus-Pirate-Dock.kicad_pcb, voltage_level_translator.kicad_sch]
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2025-12-16 Changed track widths to 1.524mm
    [ESP32-Bus-Pirate-Dock.kicad_pcb, voltage_level_translator.kicad_sch]
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2026-02-16 Modified voltage switching circuit
    [voltage_level_translator.kicad_sch]
2026-02-17 Added the inverter N-MOS
    [voltage_level_translator.kicad_sch]
2026-02-18 Changed LDO to TLV75518
    [ESP32-Bus-Pirate-Dock.kicad_sch]
2026-02-18 Modified PCB
    - Added Keepout rule for Devkit Antenna
    - Moved clone devkit header 0.2mm to better fit
    [ESP32-Bus-Pirate-Dock.kicad_pcb]
2026-02-18 Minor pcb modifications
    - Modified capacitors for multiplexers to 4.7u
    - Added bypass capacitors near TXS0108EPW VCCA and VCCB
    - Changed some text on the main schematic
    [ESP32-Bus-Pirate-Dock.kicad_pcb, ESP32-Bus-Pirate-Dock.kicad_sch, voltage_level_translator.kicad_sch]
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2026-02-20 New components PCB placement
    [ESP32-Bus-Pirate-Dock.kicad_pcb, voltage_level_translator.kicad_sch]
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2026-02-25 TS5A3157 SEL fixed
    [ESP32-Bus-Pirate-Dock.kicad_pcb, ESP32-Bus-Pirate-Dock.kicad_sch, voltage_level_translator.kicad_sch]
2026-02-26 Swapped pins for H translator
    [ESP32-Bus-Pirate-Dock.kicad_pcb, voltage_level_translator.kicad_sch]
2026-02-26 Moved power traces on inner layer 2
    [ESP32-Bus-Pirate-Dock.kicad_pcb]
2026-02-27 Changed PCB
    - Cosmetic silkscreen changes to width
    - Modified trace width of power lines to 0.508mm
    [ESP32-Bus-Pirate-Dock.kicad_pcb]
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2026-03-08 Swapped 2N7002 for 2SK2009
    [voltage_level_translator.kicad_sch]
2026-03-11 Added OSHW symbol + SN silkscreen
    [ESP32-Bus-Pirate-Dock.kicad_pcb]
2026-03-11 Added board silkscreen outlines
    [ESP32-Bus-Pirate-Dock.kicad_pcb]
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2026-03-15 Added 3D models
    - dock
    - design files for case
    - binary stls for printing
    [bottom_case.stl, enclosure.step, top_case.stl]
2026-03-17 Added layer colors & updated board version
    [ESP32-Bus-Pirate-Dock.kicad_pcb]
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2026-03-17 Added .step files for case
    [Bottom Case.step, Top Case.step]
2026-03-18 Added LCSC Parts & Board Version to v3
    [ESP32-Bus-Pirate-Dock.kicad_pcb, ESP32-Bus-Pirate-Dock.kicad_sch]
2026-03-18 Added testpoints, J3 mirrored
    - J3 mirrored in order to share the same pin numbers with CN1. It just makes it less confusing.
    - Added test points on power supplies, and SEL signals just to help test the board.
    [ESP32-Bus-Pirate-Dock.kicad_pcb, ESP32-Bus-Pirate-Dock.kicad_sch, voltage_level_translator.kicad_sch]
2026-03-19 Modified test pads & added TC2050
    [ESP32-Bus-Pirate-Dock.kicad_pcb, ESP32-Bus-Pirate-Dock.kicad_sch, voltage_level_translator.kicad_sch]
2026-03-19 Changed VTarget to Vio
    [ESP32-Bus-Pirate-Dock.kicad_pcb, ESP32-Bus-Pirate-Dock.kicad_sch, voltage_level_translator.kicad_sch]
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2026-04-08 Minor schematic changes
    - Added net classes
    - Added cosmetic changes
    [ESP32-Bus-Pirate-Dock.kicad_sch, voltage_level_translator.kicad_sch]
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
